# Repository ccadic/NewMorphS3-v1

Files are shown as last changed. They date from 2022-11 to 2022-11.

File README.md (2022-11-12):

# NewMorphS3-v1
SMall S3 DEV Board with PSP Joystick
@sulfuroid

Hi all this is the NEW MorphS3 with ESP32S3 wroom chip.
You get a battery charger on board - Most of the GPIOS available
You have a 176x320 IPS ST7789 Display (compatible with TFT_eSPI 
There is a small PSP1000 joystick to help you make games
USB connection is a SMD USB C

Heve fun.

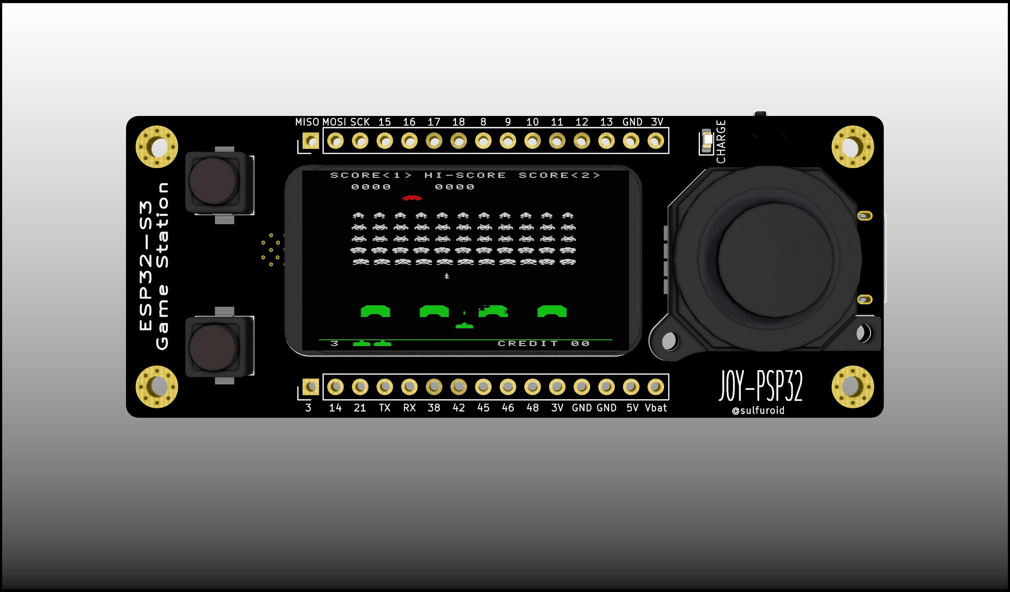
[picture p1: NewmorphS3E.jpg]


BOM and links to the components: https://github.com/ccadic/NewMorphS3-v1/blob/main/NewmorphS3-BOM.xlsx

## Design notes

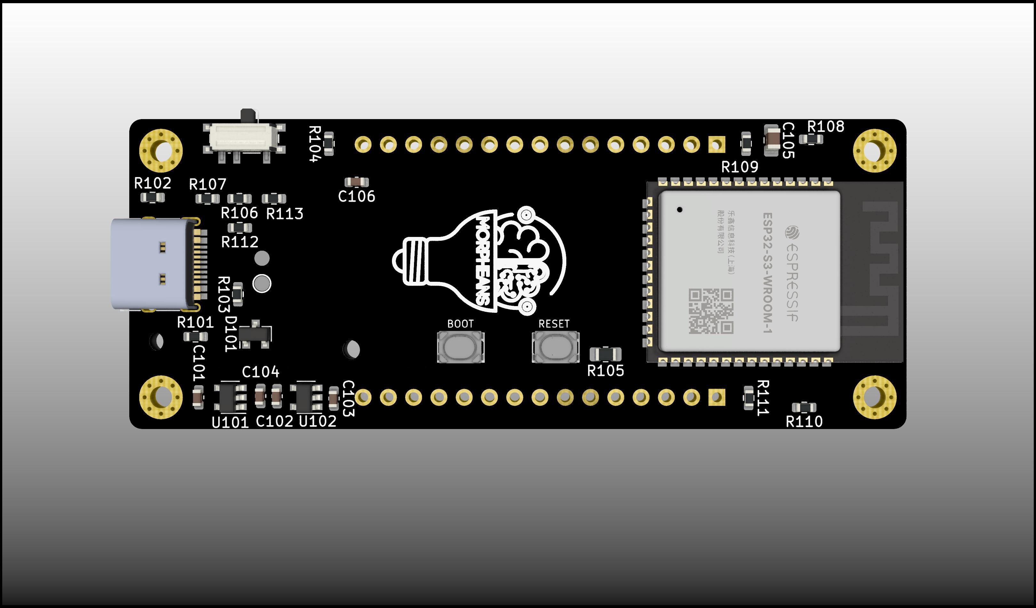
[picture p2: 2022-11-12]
NewmorphS3D.jpg

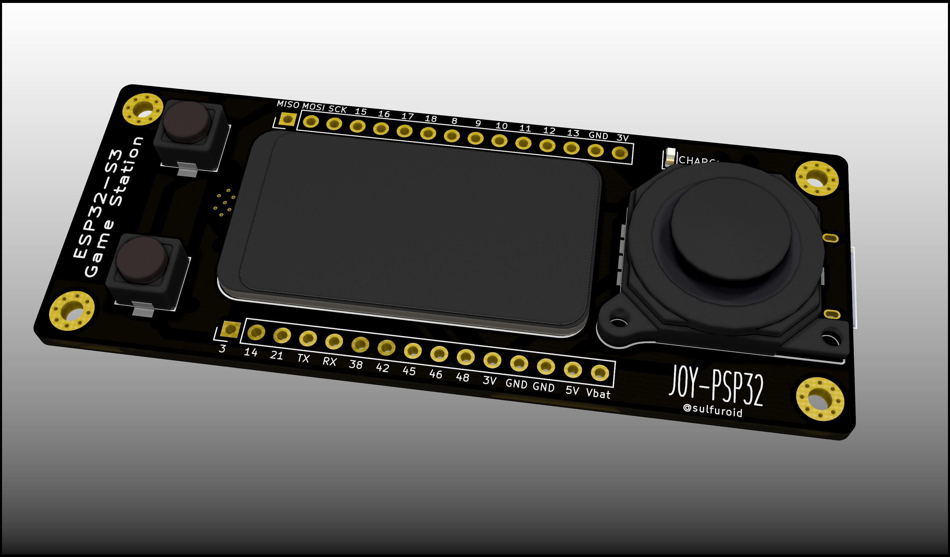
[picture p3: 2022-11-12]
NewmorphS3beta2.jpg

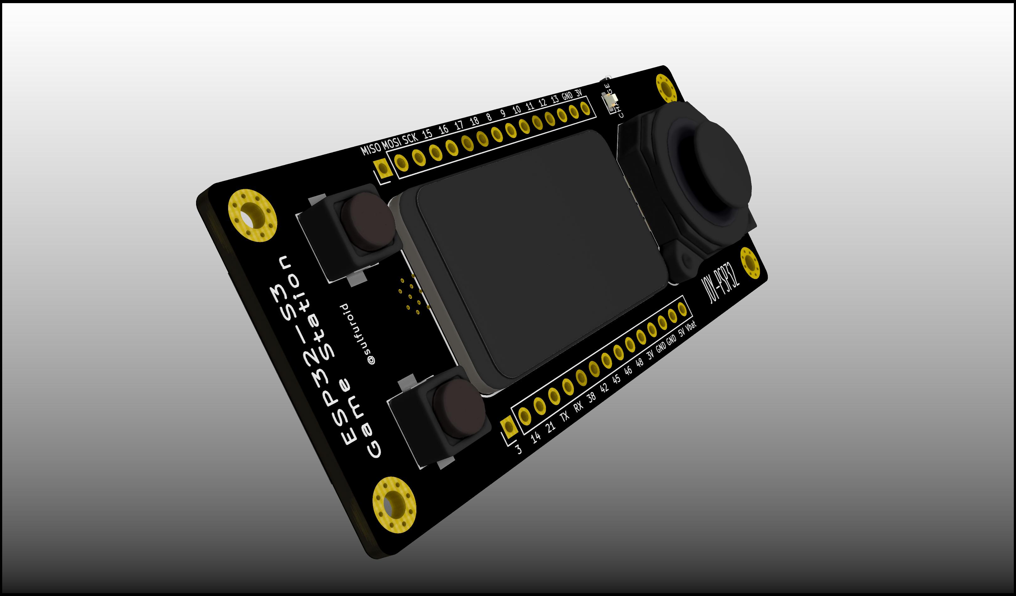
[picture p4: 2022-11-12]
NewmorphS3.bjpg.jpg

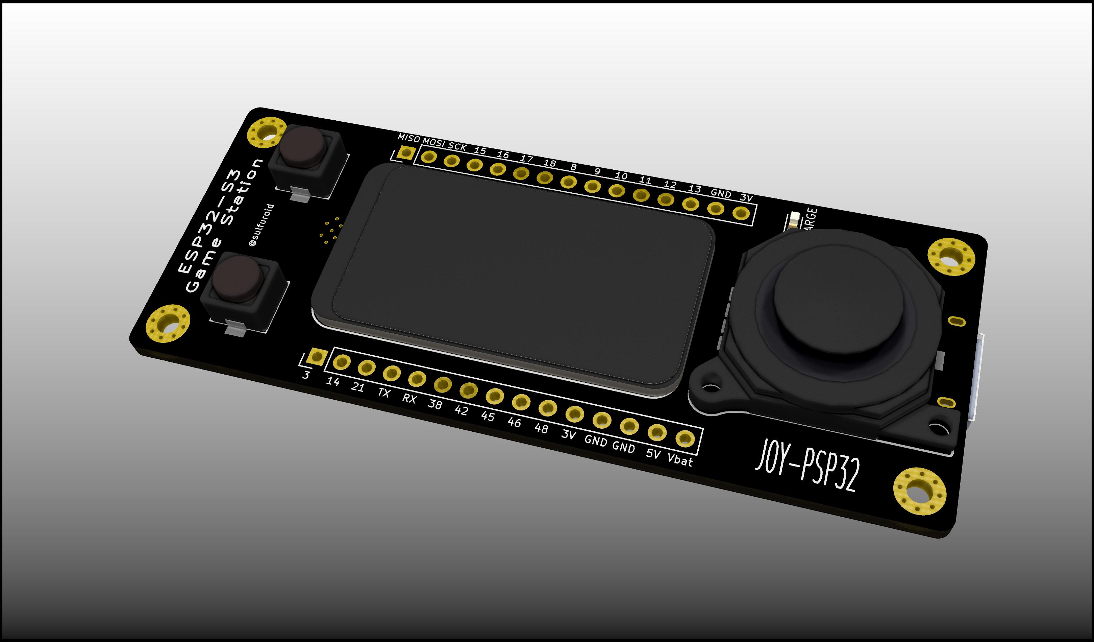
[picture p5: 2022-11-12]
NewmorphS3.jpg

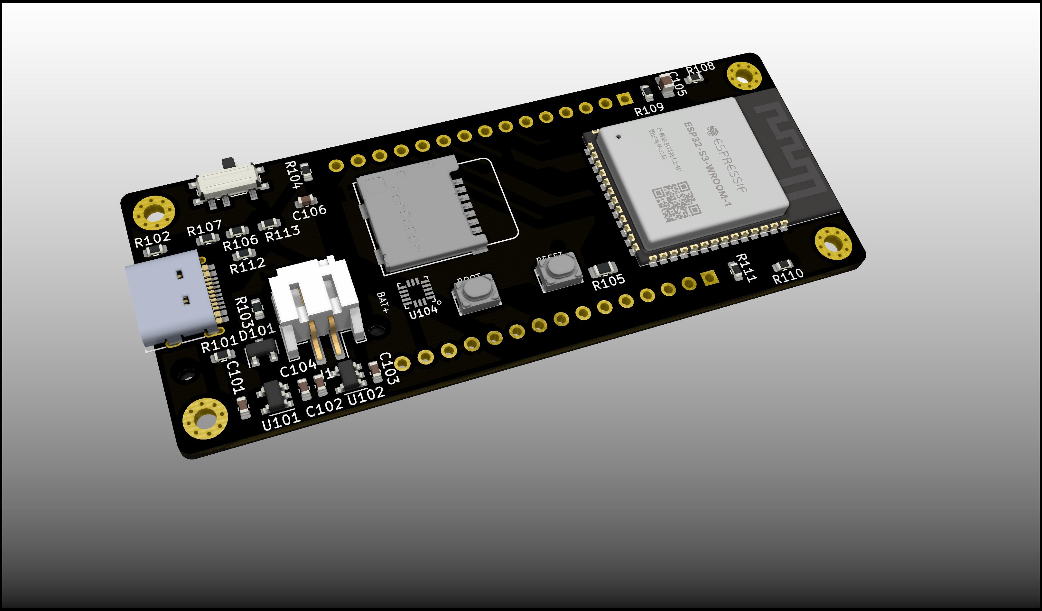
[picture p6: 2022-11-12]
MicroSDNewmorphS3.jpg

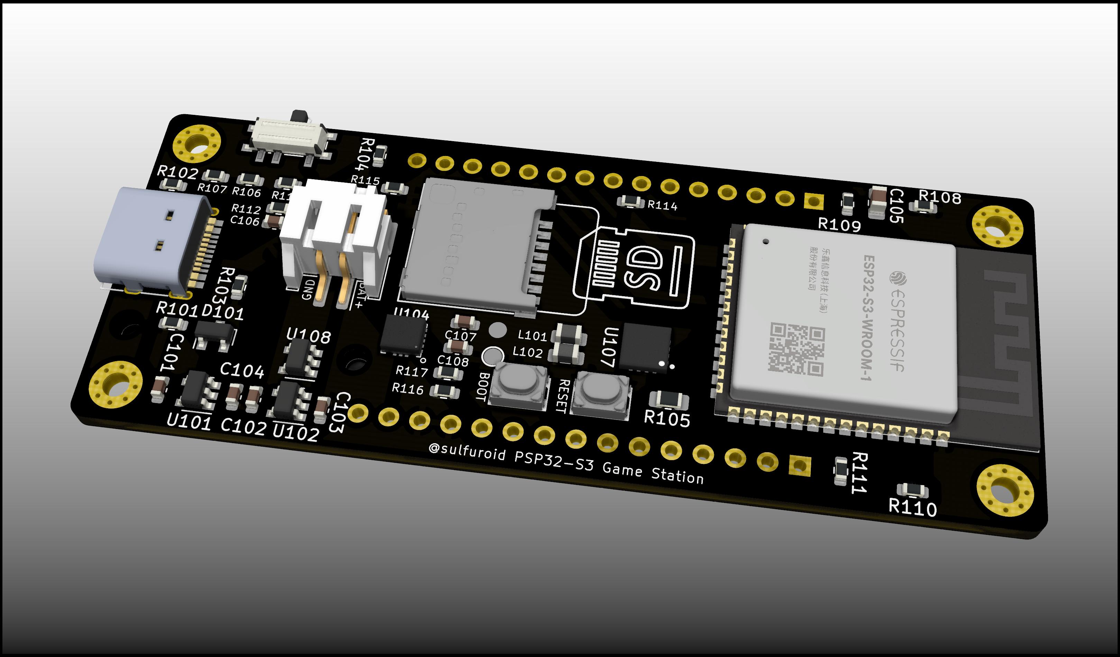
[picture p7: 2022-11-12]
NewmorphS3beta1.jpg

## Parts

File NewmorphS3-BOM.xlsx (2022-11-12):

Comment,Designator,Footprint,LCSC
1uF | C102,C103 | Capacitor_SMD:C_0603_1608Metric
4.7uF | C101,C104 | Capacitor_SMD:C_0603_1608Metric
100nF | C105 | Capacitor_SMD:C_0805_2012Metric_Pad1.18x1.45mm_HandSolder
100nF | C106 | Capacitor_SMD:C_0603_1608Metric
BAT54C | D101 | Package_TO_SOT_SMD:SOT-23
CHARGE | D102 | LED_SMD:LED_0603_1608Metric
MountingHole | H101,H102,H103,H104 | MountingHole:MountingHole_2.2mm_M2_Pad_Via
USB_C_Receptacle | J101 | 27sharp:GT-USB-7010 | https://fr.aliexpress.com/item/1005001283294686.html
BATCON | J102 | Connector_JST:JST_PH_S2B-PH-SM4-TB_1x02-1MP_P2.00mm_Horizontal | https://fr.aliexpress.com/item/1005001664001210.html
GPIOLINE1 | J103 | Connector_PinHeader_2.54mm:PinHeader_1x15_P2.54mm_Vertical
GPIOLINE2 | J104 | Connector_PinHeader_2.54mm:PinHeader_1x15_P2.54mm_Vertical
3k | R101 | Resistor_SMD:R_0603_1608Metric
5.1k | R102,R103 | Resistor_SMD:R_0603_1608Metric
470R | R104 | Resistor_SMD:R_0603_1608Metric
10k | R105 | Resistor_SMD:R_0805_2012Metric_Pad1.20x1.40mm_HandSolder
500 R | R106 | Resistor_SMD:R_0603_1608Metric
2K | R107 | Resistor_SMD:R_0603_1608Metric
10k | R108,R110 | Resistor_SMD:R_0603_1608Metric
1K | R109,R111 | Resistor_SMD:R_0603_1608Metric
22R | R112,R113 | Resistor_SMD:R_0603_1608Metric
RST | SW101 | 27sharp:SKRPABE010 | https://fr.aliexpress.com/item/32728256843.html
BOOT | SW102 | 27sharp:SKRPABE010 | https://fr.aliexpress.com/item/32728256843.html
BUT1 | SW103 | 18650:SW_TP1003 | https://fr.aliexpress.com/item/32820232659.html
BUT2 | SW104 | 18650:SW_TP1003 | https://fr.aliexpress.com/item/32820232659.html
ON-OFF | SW105 | Button_Switch_SMD:SW_SPDT_PCM12 | https://fr.aliexpress.com/item/32770868105.html
MCP73831-2-OT | U101 | Package_TO_SOT_SMD:SOT-23-5
ME6211C33M5G-N | U102 | Package_TO_SOT_SMD:SOT-23-5
ESP32S3-Wroom | U103 | 27sharp:ESP32-S3-wrooom | https://fr.aliexpress.com/item/32901557709.html
JoyStickP1000 | U105 | 27sharp:JoystickP1000 | https://fr.aliexpress.com/item/1005004379601141.html
176x320tft_176x320TFT | U106 | 27sharp:ST7789-176x320 | https://fr.aliexpress.com/item/1005003099340799.html

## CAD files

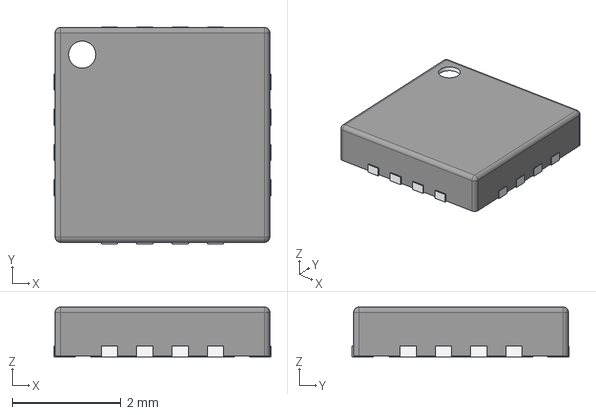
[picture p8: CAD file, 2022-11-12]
QFN-16 (4x4x0.9).step
4.00 x 4.00 x 0.92 mm

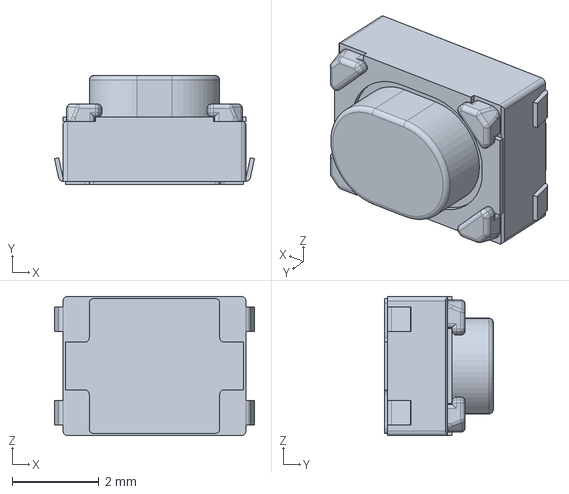
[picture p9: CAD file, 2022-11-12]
SKRPABE010.step
4.60 x 2.50 x 3.20 mm

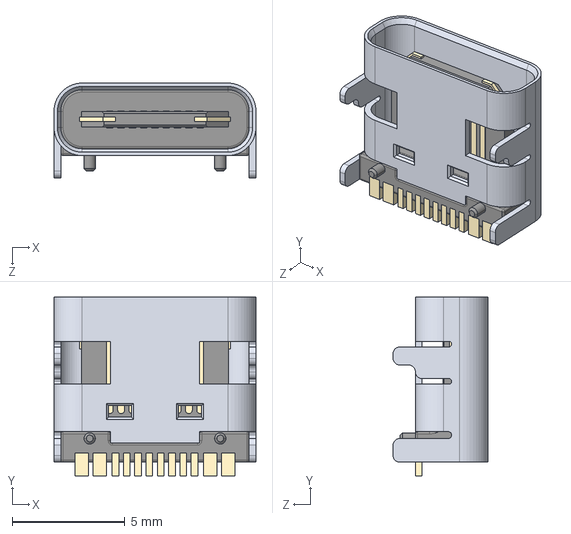
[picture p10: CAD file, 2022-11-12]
USB Type C Port (SMD Type).STEP
8.94 x 7.90 x 4.20 mm

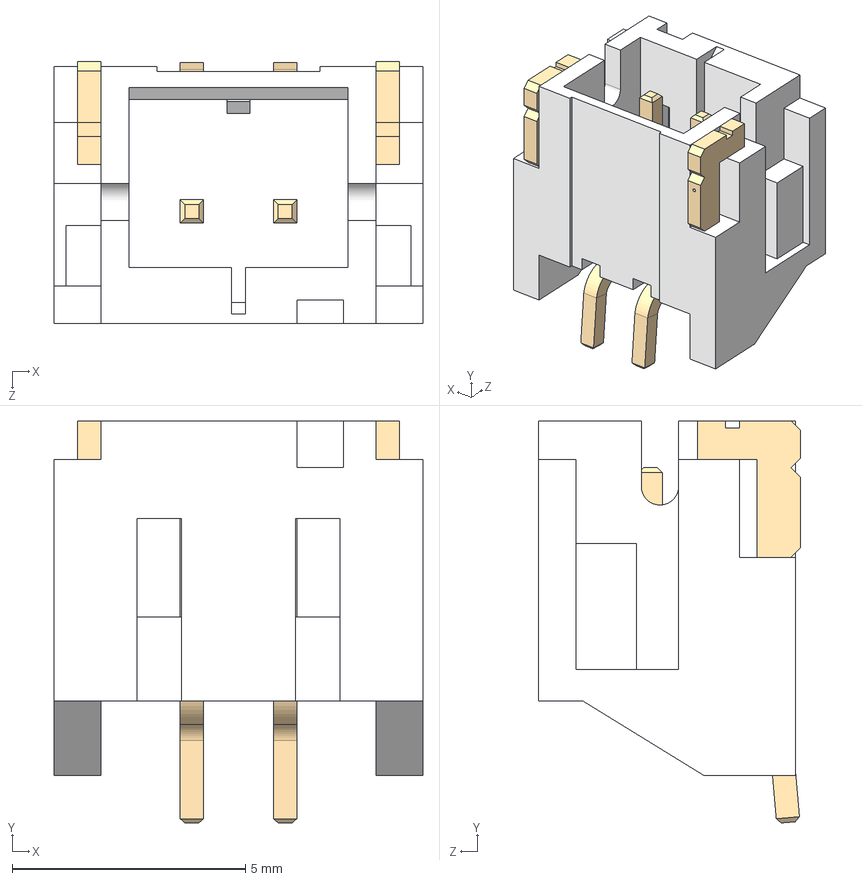
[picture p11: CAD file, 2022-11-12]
JST-S2B-PH-SM4-TB.STEP
7.90 x 8.61 x 5.61 mm

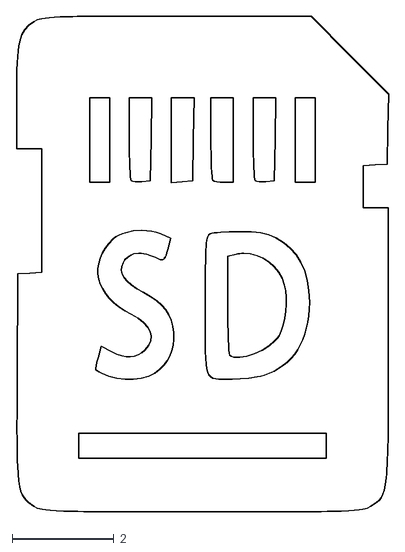
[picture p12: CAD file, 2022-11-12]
microsd.dxf
7.32 x 9.76

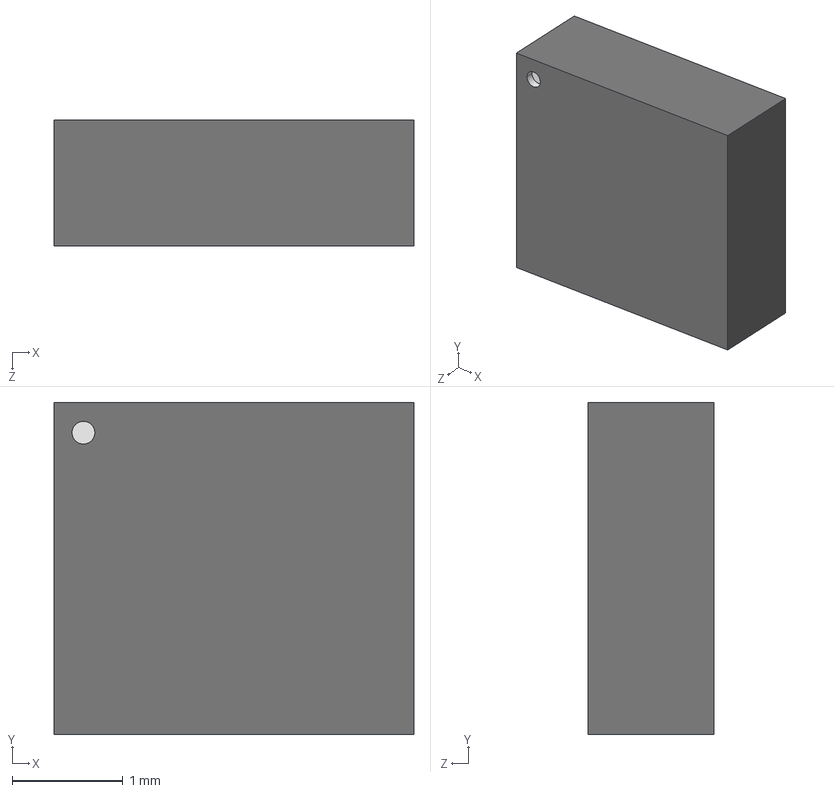
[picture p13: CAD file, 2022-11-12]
ADXL362.STEP
3.25 x 3.00 x 1.14 mm

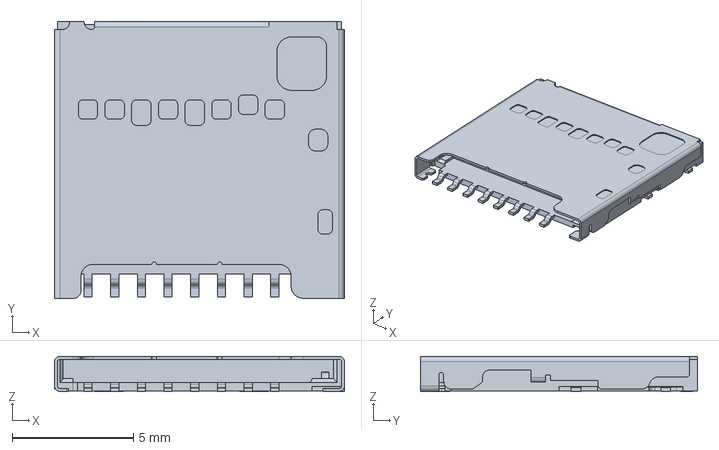
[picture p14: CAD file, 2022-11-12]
1040310811.stp
11.9 x 11.4 x 1.45 mm

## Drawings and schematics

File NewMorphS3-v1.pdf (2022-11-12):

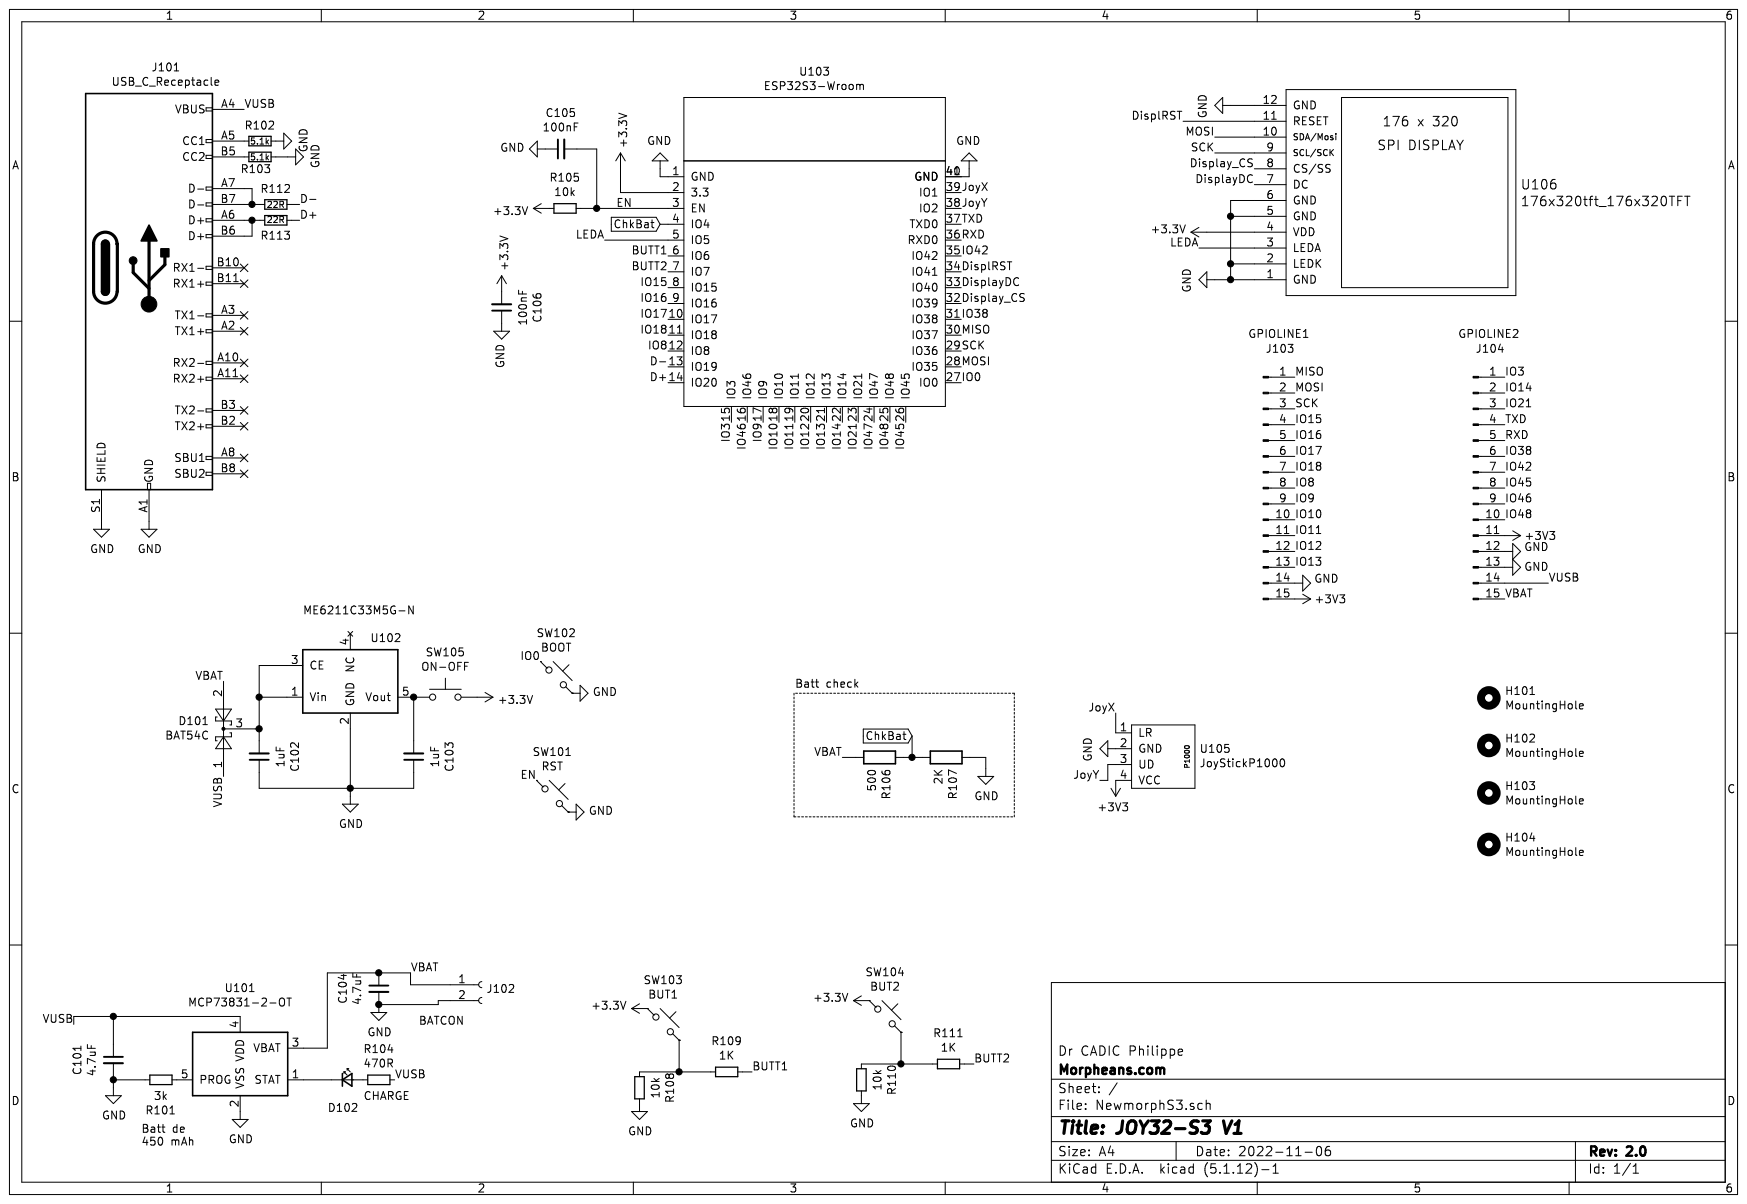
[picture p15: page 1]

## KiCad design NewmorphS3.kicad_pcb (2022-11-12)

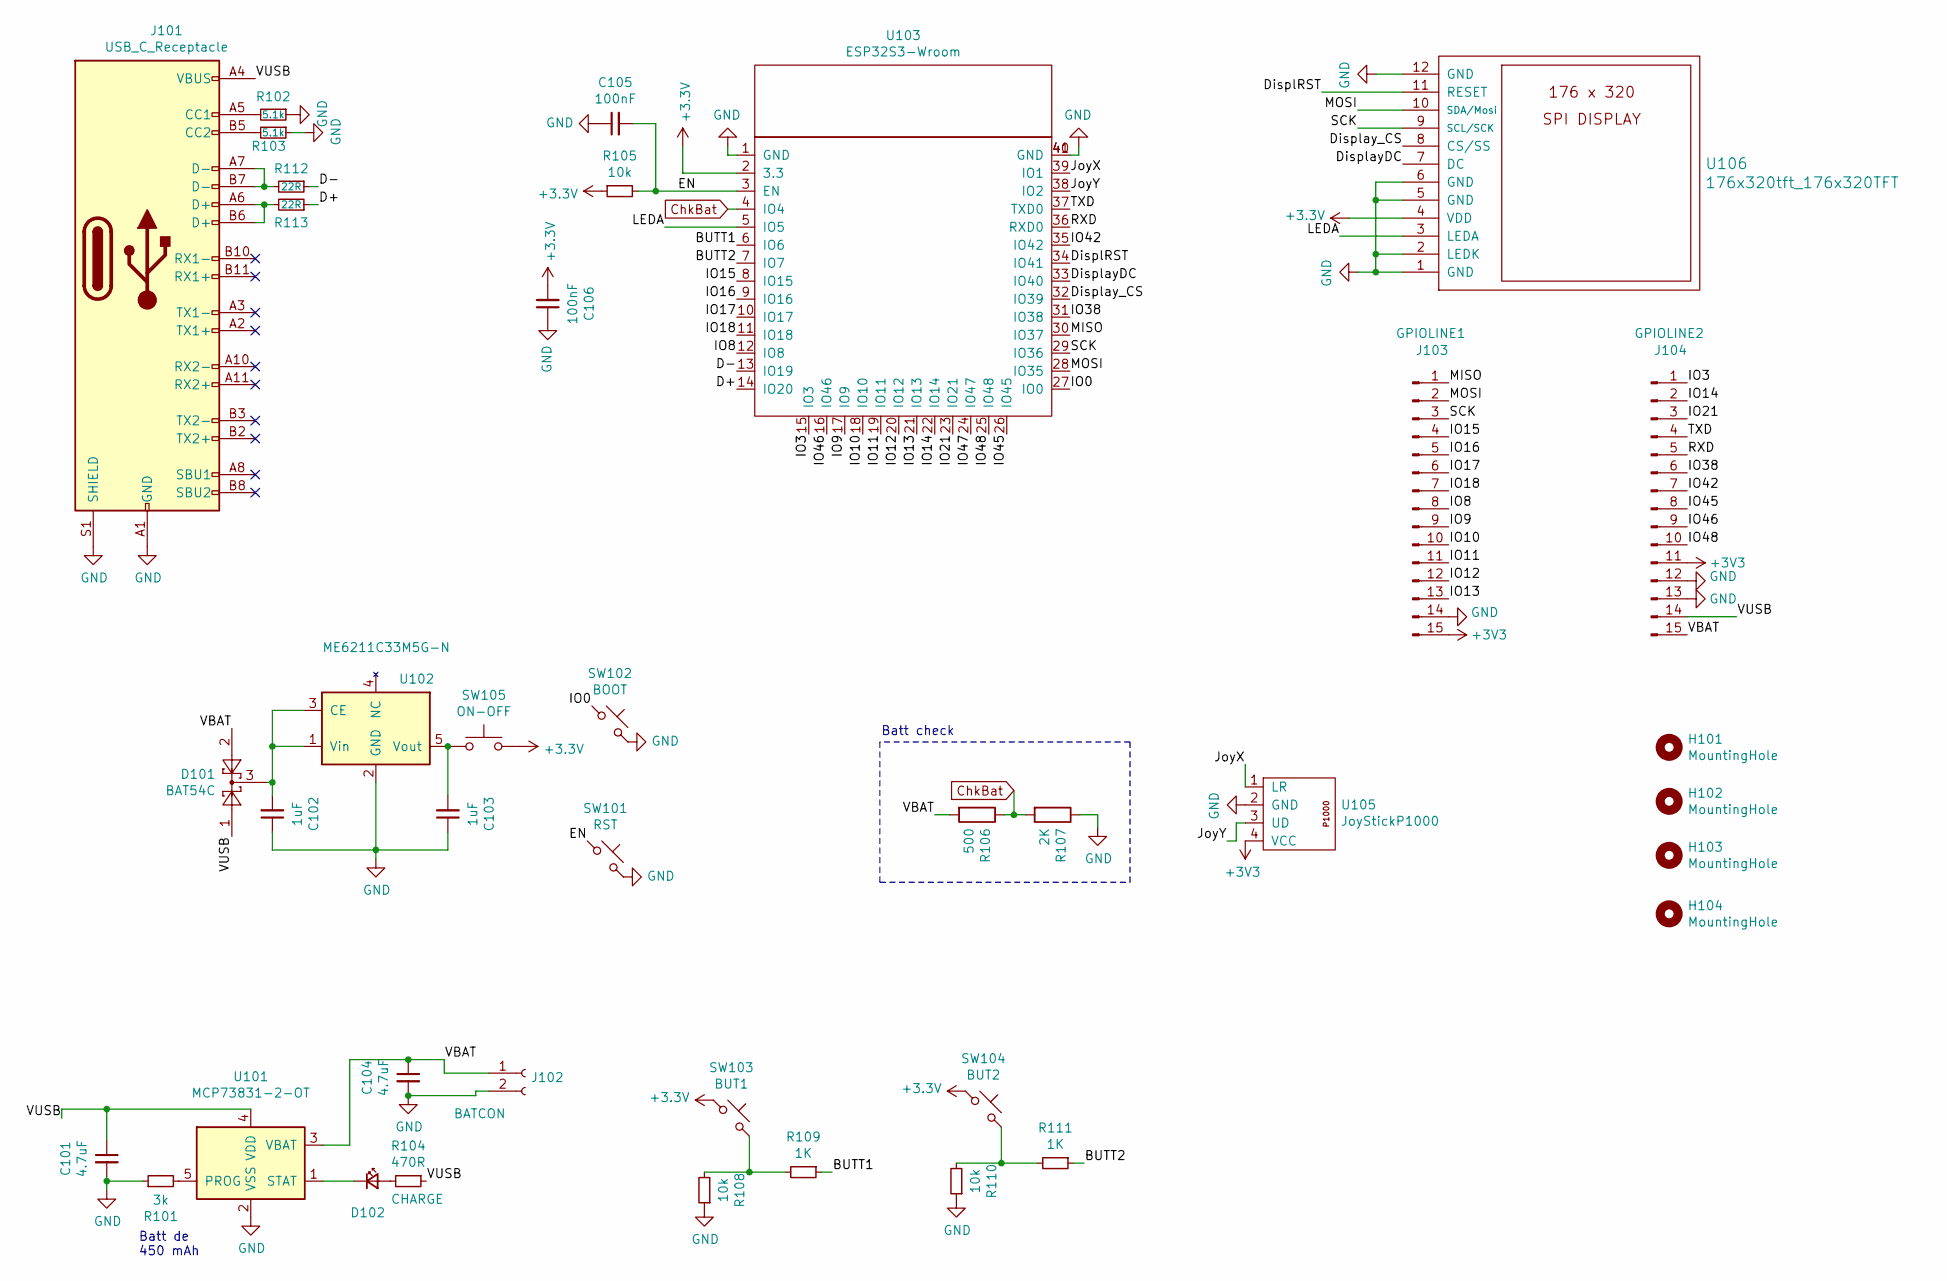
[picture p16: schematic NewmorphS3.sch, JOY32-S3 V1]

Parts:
C101, C104: 4.7uF; C_0603_1608Metric
C102, C103: 1uF; C_0603_1608Metric
C105: 100nF; C_0805_2012Metric_Pad1.18x1.45mm_HandSolder
C106: 100nF; C_0603_1608Metric
D101: BAT54C; SOT-23
D102: CHARGE; LED_0603_1608Metric
H101, H102, H103, H104: MountingHole; MountingHole_2.2mm_M2_Pad_Via
J101: USB_C_Receptacle; GT-USB-7010
J102: BATCON; JST_PH_S2B-PH-SM4-TB_1x02-1MP_P2.00mm_Horizontal
J103: GPIOLINE1; PinHeader_1x15_P2.54mm_Vertical
J104: GPIOLINE2; PinHeader_1x15_P2.54mm_Vertical
R101: 3k; R_0603_1608Metric
R102, R103: 5.1k; R_0603_1608Metric
R104: 470R; R_0603_1608Metric
R105: 10k; R_0805_2012Metric_Pad1.20x1.40mm_HandSolder
R106: 500; R_0603_1608Metric
R107: 2K; R_0603_1608Metric
R108, R110: 10k; R_0603_1608Metric
R109, R111: 1K; R_0603_1608Metric
R112, R113: 22R; R_0603_1608Metric
SW101: RST; SKRPABE010
SW102: BOOT; SKRPABE010
SW103: BUT1; SW_TP1003
SW104: BUT2; SW_TP1003
SW105: ON-OFF; SW_SPDT_PCM12
U101: MCP73831-2-OT; SOT-23-5
U102: ME6211C33M5G-N; SOT-23-5
U103: ESP32S3-Wroom; ESP32-S3-wrooom
U105: JoyStickP1000; JoystickP1000
U106: 176x320tft_176x320TFT; ST7789-176x320

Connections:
/BUTT1: R109.1, U103.6 (IO6)
/BUTT2: R111.1, U103.7 (IO7)
/D+: R113.1, U103.14 (IO20)
/D-: R112.1, U103.13 (IO19)
/DisplRST: U103.34 (IO41), U106.11 (RESET)
/DisplayDC: U103.33 (IO40), U106.7 (DC)
/Display_CS: U103.32 (IO39), U106.8 (CS/SS)
/EN: C105.2, R105.2, SW101.1, U103.3 (EN)
/IO0: SW102.1, U103.27 (IO0)
/IO3: J104.1, U103.15 (IO3)
/IO8: J103.8, U103.12 (IO8)
/IO9: J103.9, U103.17 (IO9)
/IO10: J103.10, U103.18 (IO10)
/IO11: J103.11, U103.19 (IO11)
/IO12: J103.12, U103.20 (IO12)
/IO13: J103.13, U103.21 (IO13)
/IO14: J104.2, U103.22 (IO14)
/IO15: J103.4, U103.8 (IO15)
/IO16: J103.5, U103.9 (IO16)
/IO17: J103.6, U103.10 (IO17)
/IO18: J103.7, U103.11 (IO18)
/IO21: J104.3, U103.23 (IO21)
/IO38: J104.6, U103.31 (IO38)
/IO42: J104.7, U103.35 (IO42)
/IO45: J104.8, U103.26 (IO45)
/IO46: J104.9, U103.16 (IO46)
/IO48: J104.10, U103.25 (IO48)
/JoyX: U103.39 (IO1), U105.1 (LR)
/JoyY: U103.38 (IO2), U105.3 (UD)
/LEDA: U103.5 (IO5), U106.3 (LEDA)
/MISO: J103.1, U103.30 (IO37)
/MOSI: J103.2, U103.28 (IO35), U106.10 (SDA/Mosi)
/RXD: J104.5, U103.36 (RXD0)
/SCK: J103.3, U103.29 (IO36), U106.9 (SCL/SCK)
/TXD: J104.4, U103.37 (TXD0)
/VBAT: C104.1, D101.2, J102.1, J104.15, R106.2, U101.3 (VBAT)
/VUSB: C101.1, D101.1, J101.A4 (VBUS), J101.A9 (VBUS), J101.B4 (VBUS), J101.B9 (VBUS), J104.14, R104.1, U101.4 (VDD)
ChkBat: R106.1, R107.2, U103.4 (IO4)
GND: C101.2, C102.1, C103.1, C104.2, C105.1, C106.1, J101.A1 (GND), J101.A12 (GND), J101.B1 (GND), J101.B12 (GND), J101.S1 (SHIELD), J102.2, J103.14, J104.12, J104.13, R101.1, R102.1, R103.1, R107.1, R108.1, R110.1, SW101.2, SW102.2, U101.2 (VSS), U102.2 (GND), U103.1 (GND), U103.40 (GND), U103.41 (GND), U105.2 (GND), U106.1 (GND), U106.2 (LEDK), U106.5 (GND), U106.6 (GND), U106.12 (GND)
unnamed: C102.2, D101.3, U102.1 (Vin), U102.3 (CE)
unnamed: C103.2, SW105.1, U102.5 (Vout)
unnamed: D102.1 (K), U101.1 (STAT)
unnamed: D102.2 (A), R104.2
unnamed: J101.A5 (CC1), R102.2
unnamed: J101.A6 (D+), J101.B6 (D+), R113.2
unnamed: J101.A7 (D-), J101.B7 (D-), R112.2
unnamed: J101.B5 (CC2), R103.2
unnamed: R101.2, U101.5 (PROG)
unnamed: R108.2, R109.2, SW103.2
unnamed: R110.2, R111.2, SW104.2

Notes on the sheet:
Batt de 450 mAh
Batt check

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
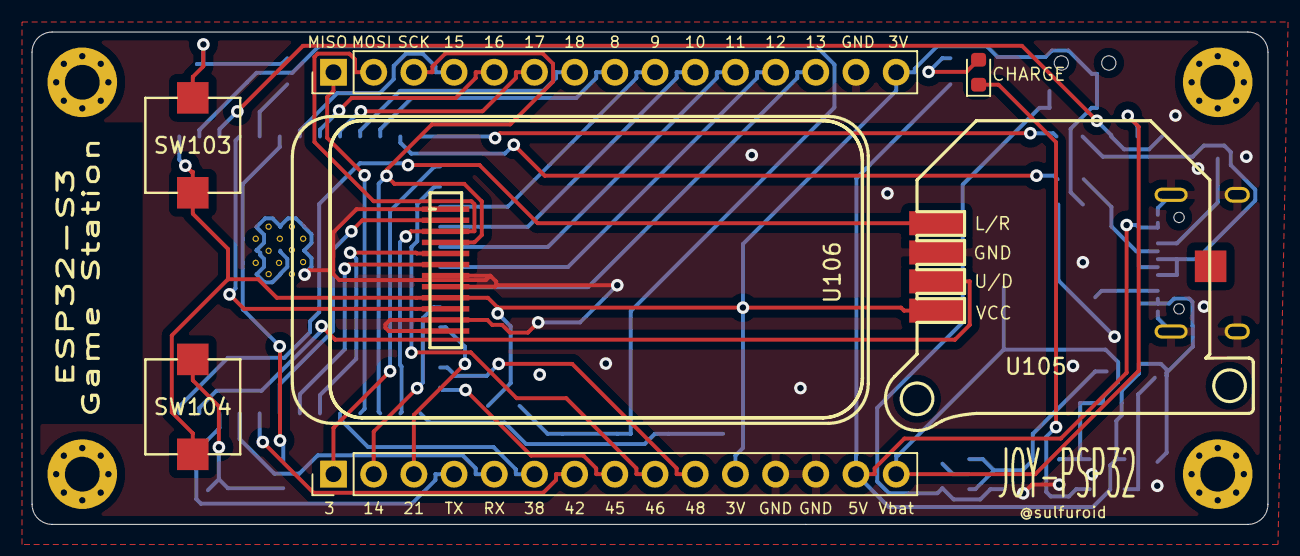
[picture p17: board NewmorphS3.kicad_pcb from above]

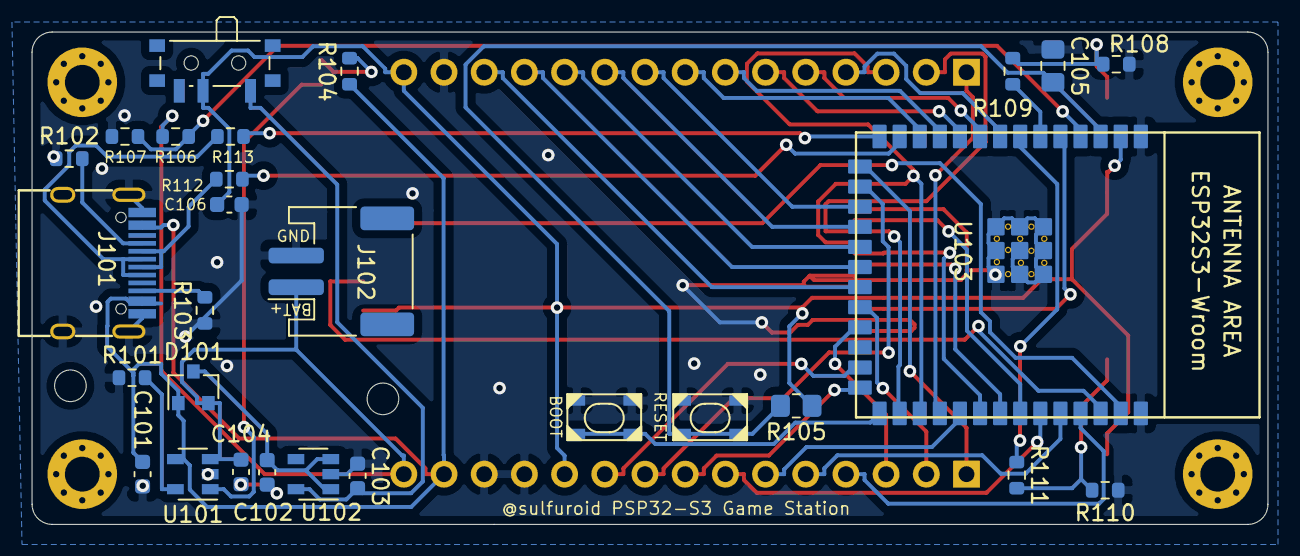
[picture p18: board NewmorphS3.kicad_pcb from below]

Board: 2 copper layers, 78.1 x 31.1 mm, 39 parts (28 on the bottom side), 51 nets.

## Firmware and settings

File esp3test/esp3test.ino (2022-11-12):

/**************************************************************************
  This is a library for several Adafruit displays based on ST77* drivers.

  Works with the Adafruit 1.8" TFT Breakout w/SD card
    ----> http://www.adafruit.com/products/358
  The 1.8" TFT shield
    ----> https://www.adafruit.com/product/802
  The 1.44" TFT breakout
    ----> https://www.adafruit.com/product/2088
  The 1.14" TFT breakout
  ----> https://www.adafruit.com/product/4383
  The 1.3" TFT breakout
  ----> https://www.adafruit.com/product/4313
  The 1.54" TFT breakout
    ----> https://www.adafruit.com/product/3787
  The 1.69" TFT breakout
    ----> https://www.adafruit.com/product/5206
  The 2.0" TFT breakout
    ----> https://www.adafruit.com/product/4311
  as well as Adafruit raw 1.8" TFT display
    ----> http://www.adafruit.com/products/618

  Check out the links above for our tutorials and wiring diagrams.
  These displays use SPI to communicate, 4 or 5 pins are required to
  interface (RST is optional).

  Adafruit invests time and resources providing this open source code,
  please support Adafruit and open-source hardware by purchasing
  products from Adafruit!

  Written by Limor Fried/Ladyada for Adafruit Industries.
  MIT license, all text above must be included in any redistribution
 **************************************************************************/

#include <Adafruit_GFX.h>    // Core graphics library
#include <Adafruit_ST7735.h> // Hardware-specific library for ST7735
#include <Adafruit_ST7789.h> // Hardware-specific library for ST7789
#include <SPI.h>

#if defined(ARDUINO_FEATHER_ESP32) // Feather Huzzah32
  #define TFT_CS         39
  #define TFT_RST        41
  #define TFT_DC         40

#elif defined(ESP8266)
  #define TFT_CS         39
  #define TFT_RST        41                                            
  #define TFT_DC         40

#else
  // For the breakout board, you can use any 2 or 3 pins.
  // These pins will also work for the 1.8" TFT shield.
  #define TFT_CS        39
  #define TFT_RST        41 // Or set to -1 and connect to Arduino RESET pin
  #define TFT_DC         40
#endif

// OPTION 1 (recommended) is to use the HARDWARE SPI pins, which are unique
// to each board and not reassignable. For Arduino Uno: MOSI = pin 11 and
// SCLK = pin 13. This is the fastest mode of operation and is required if
// using the breakout board's microSD card.

// For 1.44" and 1.8" TFT with ST7735 use:
//Adafruit_ST7735 tft = Adafruit_ST7735(TFT_CS, TFT_DC, TFT_RST);

// For 1.14", 1.3", 1.54", 1.69", and 2.0" TFT with ST7789:
//Adafruit_ST7789 tft = Adafruit_ST7789(TFT_CS, TFT_DC, TFT_RST);


// OPTION 2 lets you interface the display using ANY TWO or THREE PINS,
// tradeoff being that performance is not as fast as hardware SPI above.
#define TFT_MOSI 35  // Data out
#define TFT_SCLK 36  // Clock out
#define TFT_LEDA 5 // power LED Display Background

// For ST7735-based displays, we will use this call
//Adafruit_ST7735 tft = Adafruit_ST7735(TFT_CS, TFT_DC, TFT_MOSI, TFT_SCLK, TFT_RST);

// OR for the ST7789-based displays, we will use this call
Adafruit_ST7789 tft = Adafruit_ST7789(TFT_CS, TFT_DC, TFT_MOSI, TFT_SCLK, TFT_RST);


float p = 3.1415926;

void setup(void) {
  Serial.begin(9600);
  Serial.print(F("Hello! ST77xx TFT Test"));


  // We set LEDA to HIGH  TFT_LEDA
  pinMode(TFT_LEDA, OUTPUT); 
  digitalWrite(TFT_LEDA, HIGH);
  delay (100);

  // Use this initializer if using a 1.8" TFT screen:
  //tft.initR(INITR_BLACKTAB);      // Init ST7735S chip, black tab

  // OR use this initializer if using a 1.8" TFT screen with offset such as WaveShare:
  // tft.initR(INITR_GREENTAB);      // Init ST7735S chip, green tab

  // OR use this initializer (uncomment) if using a 1.44" TFT:
  //tft.initR(INITR_144GREENTAB); // Init ST7735R chip, green tab

  // OR use this initializer (uncomment) if using a 0.96" 160x80 TFT:
  //tft.initR(INITR_MINI160x80);  // Init ST7735S mini display

  // OR use this initializer (uncomment) if using a 1.3" or 1.54" 240x240 TFT:
  //tft.init(240, 240);           // Init ST7789 240x240

  // OR use this initializer (uncomment) if using a 1.69" 280x240 TFT:
  //tft.init(240, 280);           // Init ST7789 280x240

  // OR use this initializer (uncomment) if using a 2.0" 320x240 TFT:
  //tft.init(240, 320);           // Init ST7789 320x240

  // OR use this initializer (uncomment) if using a 1.14" 240x135 TFT:
  //tft.init(135, 240);           // Init ST7789 240x135
  
  // OR use this initializer (uncomment) if using a 1.47" 172x320 TFT:
  tft.init(172, 320);           // Init ST7789 172x320

  // SPI speed defaults to SPI_DEFAULT_FREQ defined in the library, you can override it here
  // Note that speed allowable depends on chip and quality of wiring, if you go too fast, you
  // may end up with a black screen some times, or all the time.
  //tft.setSPISpeed(40000000);

  Serial.println(F("Initialized"));

  uint16_t time = millis();
  tft.fillScreen(ST77XX_BLACK);
  time = millis() - time;

  Serial.println(time, DEC);
  delay(500);

  // large block of text
  tft.fillScreen(ST77XX_BLACK);
  testdrawtext("Lorem ipsum dolor sit amet, consectetur adipiscing elit. Curabitur adipiscing ante sed nibh tincidunt feugiat. Maecenas enim massa, fringilla sed malesuada et, malesuada sit amet turpis. Sed porttitor neque ut ante pretium vitae malesuada nunc bibendum. Nullam aliquet ultrices massa eu hendrerit. Ut sed nisi lorem. In vestibulum purus a tortor imperdiet posuere. ", ST77XX_WHITE);
  delay(1000);

  // tft print function!
  tftPrintTest();
  delay(4000);

  // a single pixel
  tft.drawPixel(tft.width()/2, tft.height()/2, ST77XX_GREEN);
  delay(500);

  // line draw test
  testlines(ST77XX_YELLOW);
  delay(500);

  // optimized lines
  testfastlines(ST77XX_RED, ST77XX_BLUE);
  delay(500);

  testdrawrects(ST77XX_GREEN);
  delay(500);

  testfillrects(ST77XX_YELLOW, ST77XX_MAGENTA);
  delay(500);

  tft.fillScreen(ST77XX_BLACK);
  testfillcircles(10, ST77XX_BLUE);
  testdrawcircles(10, ST77XX_WHITE);
  delay(500);

  testroundrects();
  delay(500);

  testtriangles();
  delay(500);

  mediabuttons();
  delay(500);

  Serial.println("done");
  delay(1000);
}

void loop() {
  tft.invertDisplay(true);
  delay(500);
  tft.invertDisplay(false);
  delay(500);
}

void testlines(uint16_t color) {
  tft.fillScreen(ST77XX_BLACK);
  for (int16_t x=0; x < tft.width(); x+=6) {
    tft.drawLine(0, 0, x, tft.height()-1, color);
    delay(0);
  }
  for (int16_t y=0; y < tft.height(); y+=6) {
    tft.drawLine(0, 0, tft.width()-1, y, color);
    delay(0);
  }

  tft.fillScreen(ST77XX_BLACK);
  for (int16_t x=0; x < tft.width(); x+=6) {
    tft.drawLine(tft.width()-1, 0, x, tft.height()-1, color);
    delay(0);
  }
  for (int16_t y=0; y < tft.height(); y+=6) {
    tft.drawLine(tft.width()-1, 0, 0, y, color);
    delay(0);
  }

  tft.fillScreen(ST77XX_BLACK);
  for (int16_t x=0; x < tft.width(); x+=6) {
    tft.drawLine(0, tft.height()-1, x, 0, color);
    delay(0);
  }
  for (int16_t y=0; y < tft.height(); y+=6) {
    tft.drawLine(0, tft.height()-1, tft.width()-1, y, color);
    delay(0);
  }

  tft.fillScreen(ST77XX_BLACK);
  for (int16_t x=0; x < tft.width(); x+=6) {
    tft.drawLine(tft.width()-1, tft.height()-1, x, 0, color);
    delay(0);
  }
  for (int16_t y=0; y < tft.height(); y+=6) {
    tft.drawLine(tft.width()-1, tft.height()-1, 0, y, color);
    delay(0);
  }
}

void testdrawtext(char *text, uint16_t color) {
  tft.setCursor(0, 0);
  tft.setTextColor(color);
  tft.setTextWrap(true);
  tft.print(text);
}

void testfastlines(uint16_t color1, uint16_t color2) {
  tft.fillScreen(ST77XX_BLACK);
  for (int16_t y=0; y < tft.height(); y+=5) {
    tft.drawFastHLine(0, y, tft.width(), color1);
  }
  for (int16_t x=0; x < tft.width(); x+=5) {
    tft.drawFastVLine(x, 0, tft.height(), color2);
  }
}

void testdrawrects(uint16_t color) {
  tft.fillScreen(ST77XX_BLACK);
  for (int16_t x=0; x < tft.width(); x+=6) {
    tft.drawRect(tft.width()/2 -x/2, tft.height()/2 -x/2 , x, x, color);
  }
}

void testfillrects(uint16_t color1, uint16_t color2) {
  tft.fillScreen(ST77XX_BLACK);
  for (int16_t x=tft.width()-1; x > 6; x-=6) {
    tft.fillRect(tft.width()/2 -x/2, tft.height()/2 -x/2 , x, x, color1);
    tft.drawRect(tft.width()/2 -x/2, tft.height()/2 -x/2 , x, x, color2);
  }
}

void testfillcircles(uint8_t radius, uint16_t color) {
  for (int16_t x=radius; x < tft.width(); x+=radius*2) {
    for (int16_t y=radius; y < tft.height(); y+=radius*2) {
      tft.fillCircle(x, y, radius, color);
    }
  }
}

void testdrawcircles(uint8_t radius, uint16_t color) {
  for (int16_t x=0; x < tft.width()+radius; x+=radius*2) {
    for (int16_t y=0; y < tft.height()+radius; y+=radius*2) {
      tft.drawCircle(x, y, radius, color);
    }
  }
}

void testtriangles() {
  tft.fillScreen(ST77XX_BLACK);
  uint16_t color = 0xF800;
  int t;
  int w = tft.width()/2;
  int x = tft.height()-1;
  int y = 0;
  int z = tft.width();
  for(t = 0 ; t <= 15; t++) {
    tft.drawTriangle(w, y, y, x, z, x, color);
    x-=4;
    y+=4;
    z-=4;
    color+=100;
  }
}

void testroundrects() {
  tft.fillScreen(ST77XX_BLACK);
  uint16_t color = 100;
  int i;
  int t;
  for(t = 0 ; t <= 4; t+=1) {
    int x = 0;
    int y = 0;
    int w = tft.width()-2;
    int h = tft.height()-2;
    for(i = 0 ; i <= 16; i+=1) {
      tft.drawRoundRect(x, y, w, h, 5, color);
      x+=2;
      y+=3;
      w-=4;
      h-=6;
      color+=1100;
    }
    color+=100;
  }
}

void tftPrintTest() {
  tft.setTextWrap(false);
  tft.fillScreen(ST77XX_BLACK);
  tft.setCursor(0, 30);
  tft.setTextColor(ST77XX_RED);
  tft.setTextSize(1);
  tft.println("Hello World!");
  tft.setTextColor(ST77XX_YELLOW);
  tft.setTextSize(2);
  tft.println("Hello World!");
  tft.setTextColor(ST77XX_GREEN);
  tft.setTextSize(3);
  tft.println("Hello World!");
  tft.setTextColor(ST77XX_BLUE);
  tft.setTextSize(4);
  tft.print(1234.567);
  delay(1500);
  tft.setCursor(0, 0);
  tft.fillScreen(ST77XX_BLACK);
  tft.setTextColor(ST77XX_WHITE);
  tft.setTextSize(0);
  tft.println("Hello World!");
  tft.setTextSize(1);
  tft.setTextColor(ST77XX_GREEN);
  tft.print(p, 6);
  tft.println(" Want pi?");
  tft.println(" ");
  tft.print(8675309, HEX); // print 8,675,309 out in HEX!
  tft.println(" Print HEX!");
  tft.println(" ");
  tft.setTextColor(ST77XX_WHITE);
  tft.println("Sketch has been");
  tft.println("running for: ");
  tft.setTextColor(ST77XX_MAGENTA);
  tft.print(millis() / 1000);
  tft.setTextColor(ST77XX_WHITE);
  tft.print(" seconds.");
}

void mediabuttons() {
  // play
  tft.fillScreen(ST77XX_BLACK);
  tft.fillRoundRect(25, 10, 78, 60, 8, ST77XX_WHITE);
  tft.fillTriangle(42, 20, 42, 60, 90, 40, ST77XX_RED);
  delay(500);
  // pause
  tft.fillRoundRect(25, 90, 78, 60, 8, ST77XX_WHITE);
  tft.fillRoundRect(39, 98, 20, 45, 5, ST77XX_GREEN);
  tft.fillRoundRect(69, 98, 20, 45, 5, ST77XX_GREEN);
  delay(500);
  // play color
  tft.fillTriangle(42, 20, 42, 60, 90, 40, ST77XX_BLUE);
  delay(50);
  // pause color
  tft.fillRoundRect(39, 98, 20, 45, 5, ST77XX_RED);
  tft.fillRoundRect(69, 98, 20, 45, 5, ST77XX_RED);
  // play color
  tft.fillTriangle(42, 20, 42, 60, 90, 40, ST77XX_GREEN);
}
